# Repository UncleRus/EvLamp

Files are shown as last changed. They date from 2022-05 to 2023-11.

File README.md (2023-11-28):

# EvLamp

Clean implementation of Alex Guyver's FireLamp analogue in pure C for ESP32.

## What it does

Display beautiful effects on a multiple matrices of NxN WS2812B/SK6812/APA106/SM16703 LEDs.

### Features

- ~30 very beautiful effects from different authors, each with set of parameters
- WiFi connectivity in station or access point modes (support for DHCP/static IP addressing)
- [JSON HTTP API for remote controlling](API.md)
- Embedded webserver for remote controlling from browser
- *TODO: OTA*

## Hardware

You will need:

- ESP32 or ESP32-S3 (ESP32-S2/ESP32-C3/ESP32-C4 and others are not supported)
- One or more WS2812B/SK6812/APA106/SM16703 LED matrices
- 4 buttons:
    - Main: long press - On/Off, click - next effect
    - Up/Down: brightness up/down
    - Reset: long press - Reset settings to defaults

You can use the KiCad 7 project located in the [hardware directory](hardware) and containing
an example implementation: a schematic, a simple board and ready-made Gerber files for production
(compatible with JLCPCB requirements).

### LED matrix

The LEDs in the matrix are connected in series like a snake, starting from the bottom row:

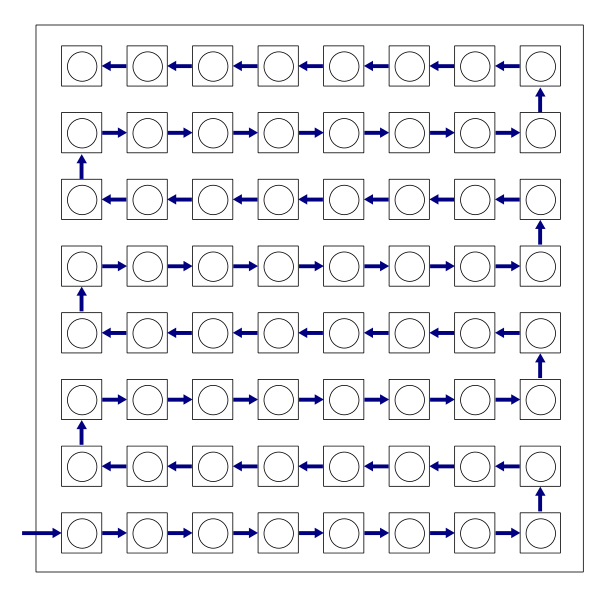
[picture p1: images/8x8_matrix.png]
8x8 matrix


The sizes of the most common matrices:
- 8x8
- 32x8
- 16x16

You can build your own matrix with widely available WS2812B/SK6812/APA106 LED strips.

The dimensions of the matrix side are limited to the range 8..128 and
number of pixels in matrix cannot be more than 1024.

I do not recommend using matrices with a large number of LEDs due to the maximum frame
rate limitations: for a matrix containing 512 LEDs, this limit is 60 fps, and for a matrix of
1024 LEDs maximal fps is 30. It is better to use multiple small matrices.

### Single matrix configuration

To control one matrix, only one GPIO pin of the microcontroller is needed:

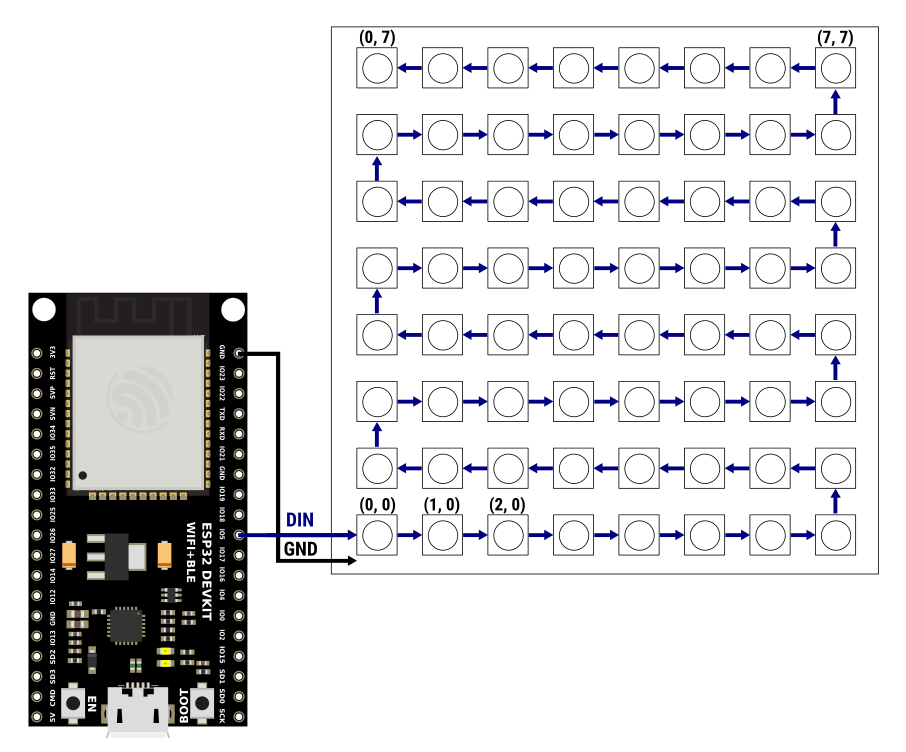
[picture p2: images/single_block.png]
Single matrix


This configuration is the simplest supported.

### Multiple LED matrices (blocks) configuration

You can connect up to 8 LED matrices of the same size to different GPIO pins and achieve high resolution
rendering of the effect. For example:

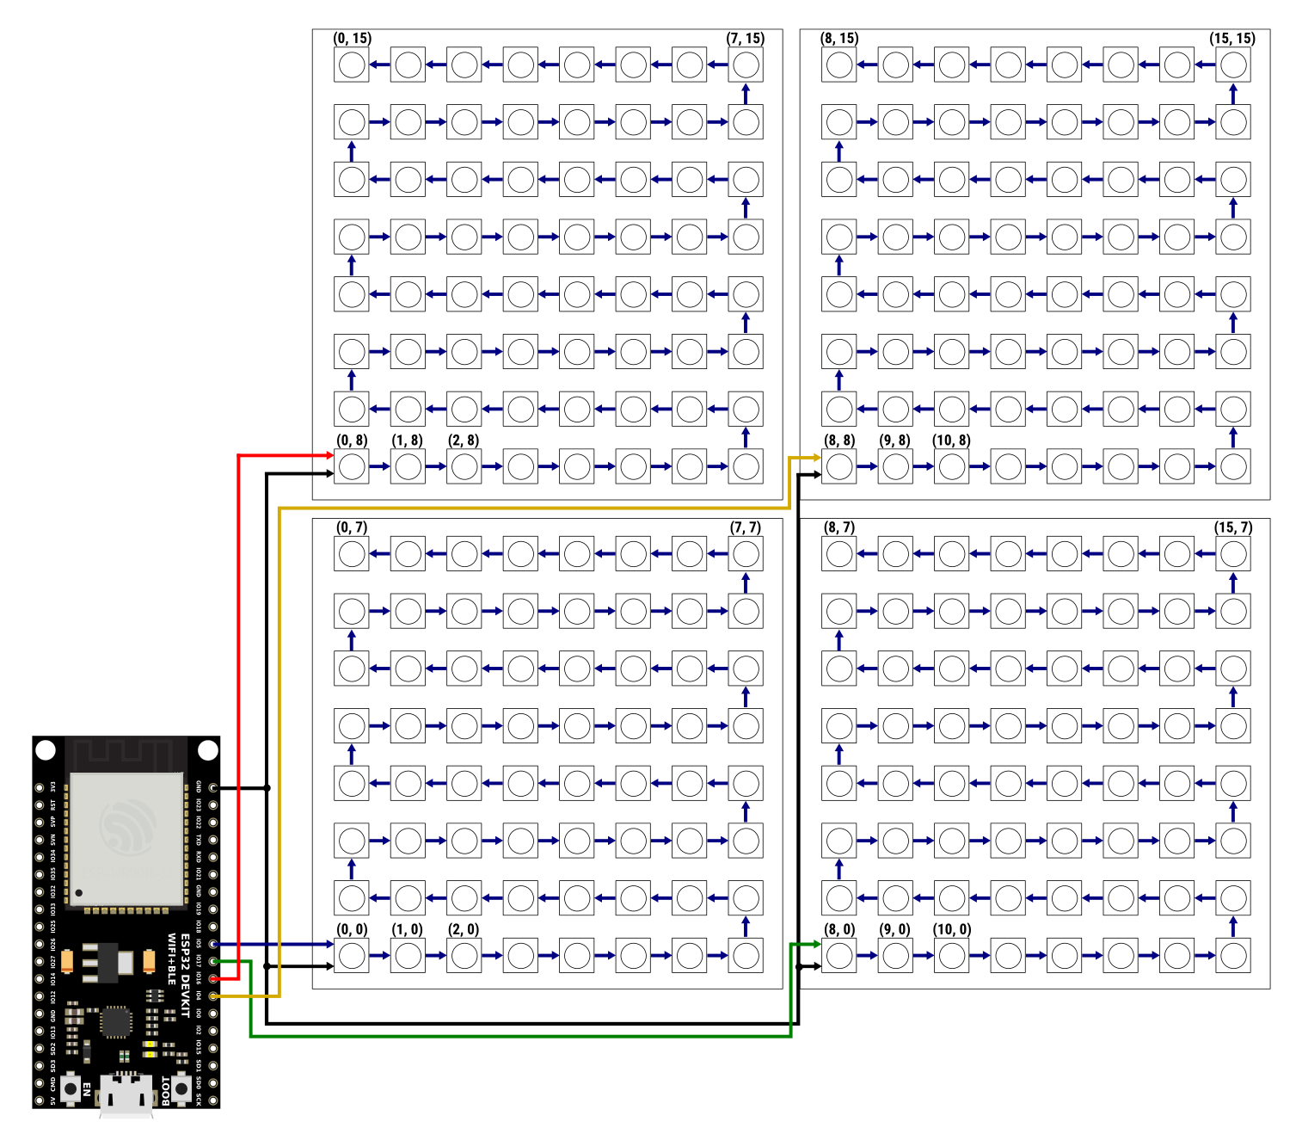
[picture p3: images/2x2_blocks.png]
4 blocks configuration example


### Minimal recommended configuration

1 block, 16x16 LEDs, 90 fps max.

### Maximal recommended configuration

2x4 blocks, each 32x16 LEDs.
Total screen dimensions: 64x64, 4096 LEDs, 60 fps max.

### Changing LED layout

Configure your LED layout at runtime by API or in browser ("Menu -> LEDs Settings"):

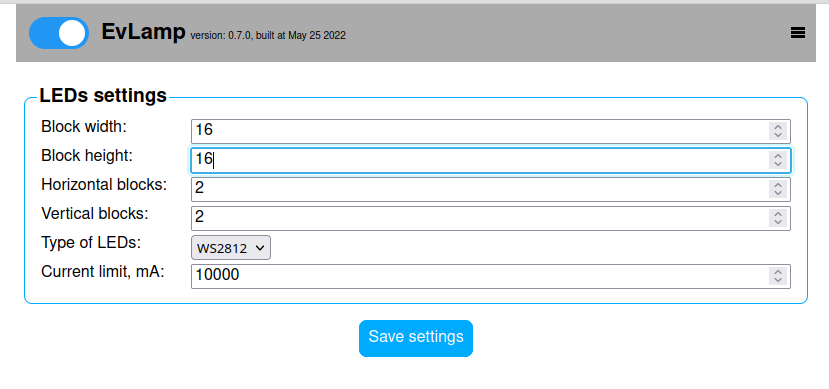
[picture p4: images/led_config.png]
LED layout configuration


## Changing default settings 

You can select GPIOs, set default WiFi config, LED layout and more in `idf.py menuconfig`
(`*** EvLamp configuration ***`). 

## How to build firmware

- Setup latest ESP-IDF master
- `git clone https://github.com/UncleRus/EvLamp.git`
- `git submodule init --recursive --remote`
- `idf.py menuconfig`
- `idf.py build`
- `idf.py erase-flash` (not necessary but recommended)
- `idf.py flash` to upload firmware to ESP

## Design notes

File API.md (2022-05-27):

# API

EvLamp provides a simple API based on HTTP GET and POST requests containing JSON data.

---

## Contents

- [Get firmware information](#get-firmware-information)
- [Get current WiFi settings](#get-current-wifi-settings)
- [Set WiFi settings](#set-wifi-settings)
- [Get current LED settings](#get-current-led-settings)
- [Set LED settings](#set-led-settings)
- [Reset system settings](#reset-system-settings)
- [Reboot device](#reboot-device)
- [Get current lamp state](#get-current-lamp-state)
- [Set lamp state](#set-lamp-state)
- [Get full list of effects and its parameters](#get-full-list-of-effects-and-its-parameters)
- [Reset parameters of all effects](#reset-parameters-of-all-effects)
- [Get current effect parameters](#get-current-effect-parameters)
- [Set effect parameters](#set-effect-parameters)

---

## Get firmware information

### Request

**GET** `/api/info`

### Response

```jsonc
{
  "app_name": <String, Application name, usually "EvLamp">,
  "app_version": <String, Application version>,
  "build_date": <String, Application build date>,
  "idf_ver": <String, Version of used ESP-IDF>
}
```

**Example**

```json
{
  "app_name": "EvLamp",
  "app_version": "0.6.3",
  "build_date": "May  2 2022",
  "idf_ver": "v5.0-dev-1829-ge29e96101d-dirty"
}
```

---

## Get current WiFi settings

### Request

**GET** `/api/settings/wifi`

### Response

```jsonc
{
  "mode": <Integer, WiFi mode. 1 - Station, 2 - Access point>,
  "ip": {
    /* IP settings for both AP and station modes */
    "dhcp": <Boolean, DHCP client enable in station mode>,
    "ip": <String, IP address. In station mode only makes sense if DHCP client is disabled>,
    "netmask": <String, Network mask. In station mode only makes sense if DHCP client is disabled>,
    "gateway": <String, Gateway IP address. In station mode only makes sense if DHCP client is disabled>,
    "dns": <String, IP-address of DNS server. In station mode only makes sense if DHCP client is disabled, 
          in AP mode used as fallback DNS server'>
  },
  "ap": {
    /* Access Point settings, only makes sense in AP mode */
    "ssid": <String, SSID of Access Point>,
    "channel": <Integer, Channel number>,
    "password": <String, Access Point WPA2 password. If empty, Access point will be in open mode>,
  },
  "sta": {
    /* Station settings, only makes sense in station mode */
    "ssid": <String, Contains the SSID of the network being connected to in station mode>,
    "password": <String, WPA2 password>,
  }
}
```

**Example**

```json
{
  "mode": 1,
  "ip": {
    "dhcp": true,
    "ip": "192.168.1.1",
    "netmask": "255.255.255.0",
    "gateway": "192.168.1.1",
    "dns": "192.168.1.1"
  },
  "ap": {
    "ssid": "EvLamp",
    "channel": 6,
    "password": ""
  },
  "sta": {
    "ssid": "MyHomeWiFi",
    "password": "SuperSecret"
  }
}
```

---

## Set WiFi settings

### Request

**POST** `/api/settings/wifi`

```jsonc
{
  "mode": <Integer, WiFi mode. 1 - Station, 2 - Access point>,
  "ip": {
    /* IP settings for both AP and station modes */
    "dhcp": <Boolean, DHCP client enable in station mode>,
    "ip": <String, IP address. In station mode only makes sense if DHCP client is disabled>,
    "netmask": <String, Network mask. In station mode only makes sense if DHCP client is disabled>,
    "gateway": <String, Gateway IP address. In station mode only makes sense if DHCP client is disabled>,
    "dns": <String, IP-address of DNS server. In station mode only makes sense if DHCP client is disabled, 
          in AP mode used as fallback DNS server'>
  },
  "ap": {
    /* Access Point settings, only makes sense in AP mode */
    "ssid": <String, SSID of Access Point>,
    "channel": <Integer, Channel number>,
    "password": <String, Access Point WPA2 password. If empty, Access point will be in open mode>,
  },
  "sta": {
    /* Station settings, only makes sense in station mode */
    "ssid": <String, Contains the SSID of the network being connected to in station mode>,
    "password": <String, WPA2 password>,
  }
}
```

### Response

```jsonc
{
  "result": <Integer, Result code. 0 - no errors>,
  "name": <String, Name of the result code, "ESP_OK" for result code 0>,
  "message": <String, Error message if result code != 0>
}
```

---

## Get current LED settings

### Request

**GET** `/api/settings/leds`

### Response

```jsonc
{
  "block_width": <Integer, single block (LED matrix) width (number of columns), 8..128>,
  "block_height": <Integer, single block (LED matrix) height (number of rows), 8..128>,
  "h_blocks": <Integer, number of blocks horizontally>,
  "v_blocks": <Integer, number of blocks vertically>,
  "type": <Integer, Type of LEDs. 0 - WS2812, 1 - SK6812, 2 - APA106, 3 - SM16703>,
  "current_limit": <Integer, Approximate limit of current consumed by all LEDs in milliamps.
                   The larger this value, the higher the maximum brightness.>,
}
```

*Note: The total number of blocks (h_blocks * v_blocks) should not be more than 8*

**Example**

Single 16x16 WS2812B matrix:

```json
{
  "block_width": 16,
  "block_height": 16,
  "h_blocks": 1,
  "v_blocks": 1,
  "type": 0,
  "current_limit": 5000
}
```

---

## Set LED settings

### Request

**POST** `/api/settings/leds`

```jsonc
{
  "block_width": <Integer, single block (LED matrix) width (number of columns), 8..128>,
  "block_height": <Integer, single block (LED matrix) height (number of rows), 8..128>,
  "h_blocks": <Integer, number of blocks horizontally>,
  "v_blocks": <Integer, number of blocks vertically>,
  "type": <Integer, Type of LEDs. 0 - WS2812, 1 - SK6812, 2 - APA106, 3 - SM16703>,
  "current_limit": <Integer, Approximate limit of current consumed by all LEDs in milliamps.
                   The larger this value, the higher the maximum brightness.>,
}
```

### Response

```jsonc
{
  "result": <Integer, Result code. 0 - no errors>,
  "name": <String, Name of the result code, "ESP_OK" for result code 0>,
  "message": <String, Error message if result code != 0>
}
```

---

## Reset system settings

Resets all system settings including both WiFi and LED settings to default values.
After resetting device must be rebooted.

### Request

**GET** `/api/settings/reset`

### Response

```jsonc
{
  "result": <Integer, Result code. 0 - no errors>,
  "name": <String, Name of the result code, "ESP_OK" for result code 0>,
  "message": <String, Error message if result code != 0>
}
```

---

## Reboot device

### Request

**GET** `/api/reboot`

### Response

No response, device just reboots.

---

## Get current lamp state

### Request

**GET** `/api/lamp/state`

### Response

```jsonc
{
  "on": <Boolean, true - Lamp is on, false - Lamp is off>,
  "effect": <Integer, Current effect ID, 0-based>,
  "brightness": <Integer, LED matrix brightness, 0..255>,
  "fps": <Integer, Frames per seconds, 0..120>
}
```

---

## Set lamp state

With this function you can switch LEDs on and off, change current effect, brightness and FPS.

### Request

**POST** `/api/lamp/state`

```jsonc
{
  "on": <Boolean, true - Lamp is on, false - Lamp is off>,
  "effect": <Integer, Selected effect ID, 0-based>,
  "brightness": <Integer, LED matrix brightness, 0..255>,
  "fps": <Integer, Frames per seconds, 0..120>
}
```

Any item in request can be omitted. For example, you can switch off the lamp with this POST:
```json
{ "on": false }
```
or change effect to "Fire" (id = 1) and set brightness:
```json
{ "effect": 1, "brightness": 50 }
```

### Response

```jsonc
{
  "result": <Integer, Result code. 0 - no errors>,
  "name": <String, Name of the result code, "ESP_OK" for result code 0>,
  "message": <String, Error message if result code != 0>
}
```

---

## Get full list of effects and its parameters

### Request

**GET** `/api/effects`

### Response

```jsonc
[
  {
    "name": <String, Effect name>,
    "params": [
      {
        "name": <String, Parameter name>,
        "min": <Integer, Minimal value>,
        "max": <Integer, Maximal value>,
        "default": <Integer, Default value>,
        "value": <Integer, Current value>
      },
      ...
    ]
  },
  ...
]
```

The effect index in the response array is the effect ID.
The parameter's index in the effect's parameter list is the parameter ID.

**Example**

```json
[{
    "name": "Color lamp",
    "params": [{
        "name": "Red",
        "min": 0,
        "max": 255,
        "default": 255,
        "value": 255
      }, {
        "name": "Green",
        "min": 0,
        "max": 255,
        "default": 159,
        "value": 159
      }, {
        "name": "Blue",
        "min": 0,
        "max": 255,
        "default": 70,
        "value": 70
      }]
  },
  {
    "name": "Fire",
    "params": [{
        "name": "Palette",
        "min": 0,
        "max": 7,
        "default": 0,
        "value": 0
      }, {
        "name": "Scale",
        "min": 10,
        "max": 100,
        "default": 60,
        "value": 60
      }]
  },
  ... 
  {
    "name": "Fireflies",
    "params": [{
        "name": "Number of fireflies",
        "min": 4,
        "max": 48,
        "default": 16,
        "value": 16
      }, {
        "name": "Chaotic movements",
        "min": 0,
        "max": 1,
        "default": 1,
        "value": 1
      }, {
        "name": "Speed",
        "min": 1,
        "max": 255,
        "default": 255,
        "value": 255
      }, {
        "name": "Update time",
        "min": 1,
        "max": 10,
        "default": 3,
        "value": 3
      }]
  }]
```

---

## Reset parameters of all effects

### Request

**GET** `/api/effects/reset`

### Response

```jsonc
{
  "result": <Integer, Result code. 0 - no errors>,
  "name": <String, Name of the result code, "ESP_OK" for result code 0>,
  "message": <String, Error message if result code != 0>
}
```

---

## Get current effect parameters

### Request

**GET** `/api/lamp/effect`

### Response

```jsonc
{
  "effect": <Integer, Current effect ID, 0-based>,
  "params": [
    {
      "name": <String, Parameter name>,
      "min": <Integer, Minimal value>,
      "max": <Integer, Maximal value>,
      "default": <Integer, Default value>,
      "value": <Integer, Current value>
    },
    ...
  ]
}
```

**Example**

```json
{
  "effect": 1,
  "params": [
    {
      "name": "Palette",
      "min": 0,
      "max": 7,
      "default": 0,
      "value": 0
    },
    {
      "name": "Scale",
      "min": 10,
      "max": 100,
      "default": 60,
      "value": 60
    }
  ]
}
```

---

## Set effect parameters

### Request

**POST** `/api/lamp/effect`

```jsonc
{
  "effect": <Integer, Effect ID, 0-based>,
  "params": [
    <Integer, 0 parameter value>,
    ...
    <Integer, n parameter value>,
  ]
}
```

**Example**

Set Palette = 1 and Scale = 60 for the "Fire" effect. 

```json
{
  "effect": 1,
  "params": [ 1, 60 ]
}
```

### Response

```jsonc
{
  "result": <Integer, Result code. 0 - no errors>,
  "name": <String, Name of the result code, "ESP_OK" for result code 0>,
  "message": <String, Error message if result code != 0>
}
```

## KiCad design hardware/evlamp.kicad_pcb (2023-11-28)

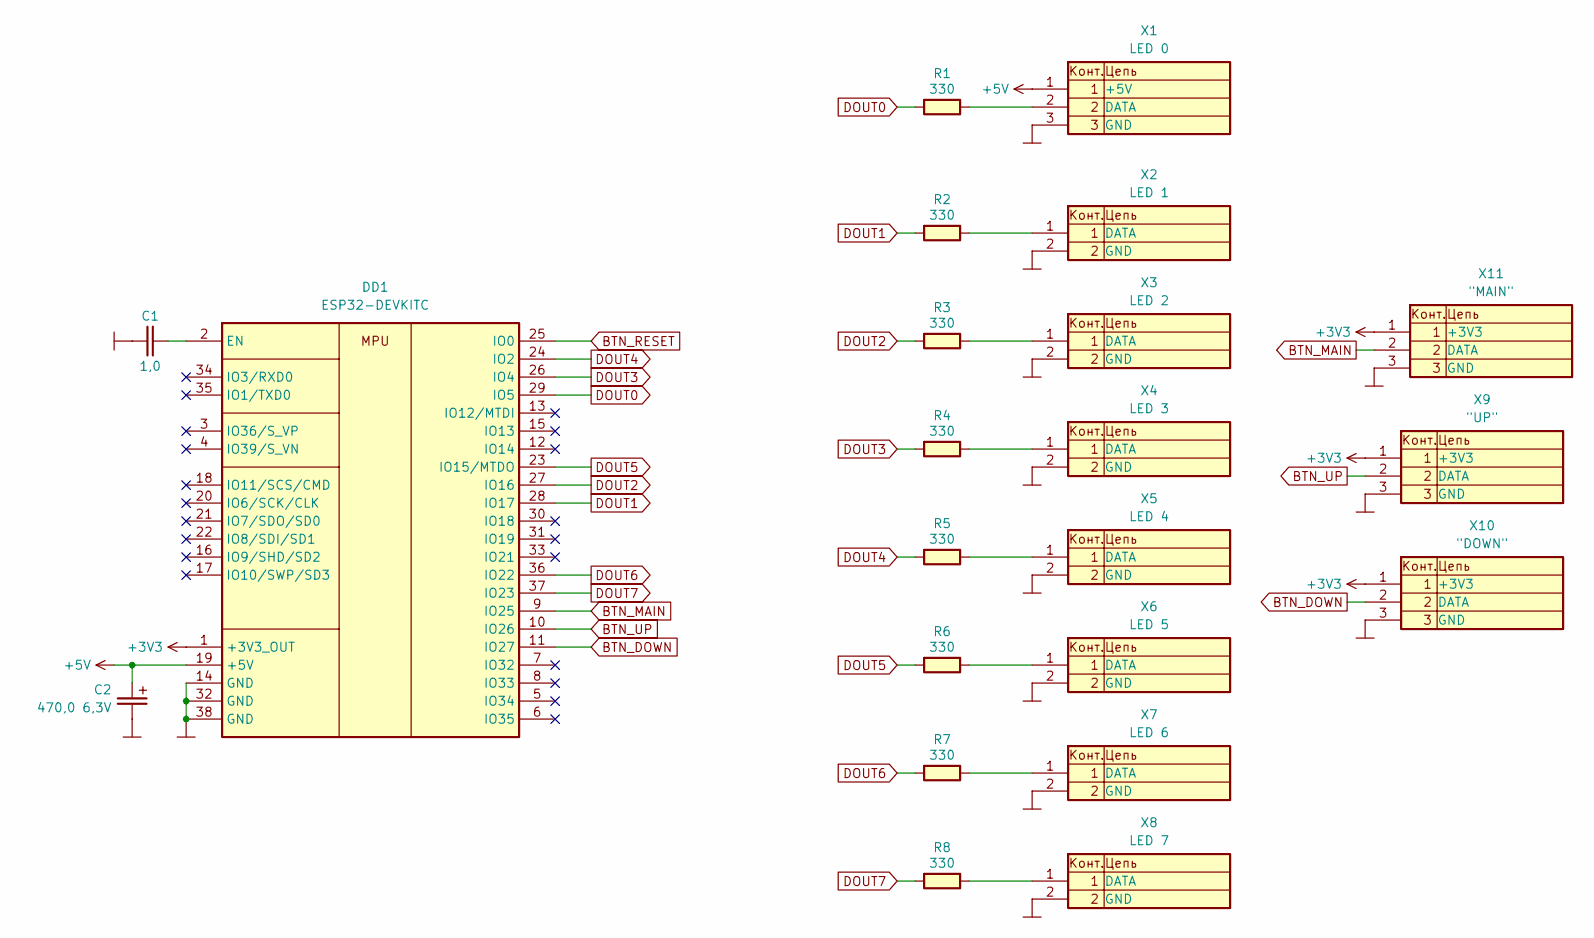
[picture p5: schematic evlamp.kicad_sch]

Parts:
C1: 1,0; C_0805_2012Metric_Pad1.18x1.45mm_HandSolder
C2: 470,0 6,3V; CP_EIA-7343-31_Kemet-D_Pad2.25x2.55mm_HandSolder
DD1: ESP32-DEVKITC
R1, R2, R3, R4, R5, R6, R7, R8: 330; R_0805_2012Metric_Pad1.20x1.40mm_HandSolder
X1: LED 0; TerminalBlock_bornier-3_P5.08mm
X2: LED 1; TerminalBlock_bornier-2_P5.08mm
X3: LED 2; TerminalBlock_bornier-2_P5.08mm
X4: LED 3; TerminalBlock_bornier-2_P5.08mm
X5: LED 4; TerminalBlock_bornier-2_P5.08mm
X6: LED 5; TerminalBlock_bornier-2_P5.08mm
X7: LED 6; TerminalBlock_bornier-2_P5.08mm
X8: LED 7; TerminalBlock_bornier-2_P5.08mm
X9: "UP"; PinHeader_1x03_P2.54mm_Vertical
X10: "DOWN"; PinHeader_1x03_P2.54mm_Vertical
X11: "MAIN"; PinHeader_1x03_P2.54mm_Vertical

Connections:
+3V3: DD1.1 (+3V3_OUT), X9.1, X10.1, X11.1
+5V: C2.1, DD1.19 (+5V), X1.1
BTN_DOWN: DD1.11 (IO27), X10.2
BTN_MAIN: DD1.9 (IO25), X11.2
BTN_RESET: DD1.25 (IO0)
BTN_UP: DD1.10 (IO26), X9.2
DOUT0: DD1.29 (IO5), R1.1 (L)
DOUT1: DD1.28 (IO17), R2.1 (L)
DOUT2: DD1.27 (IO16), R3.1 (L)
DOUT3: DD1.26 (IO4), R4.1 (L)
DOUT4: DD1.24 (IO2), R5.1 (L)
DOUT5: DD1.23 (IO15/MTDO), R6.1 (L)
DOUT6: DD1.36 (IO22), R7.1 (L)
DOUT7: DD1.37 (IO23), R8.1 (L)
GND: C1.1, C2.2, DD1.14 (GND), DD1.32 (GND), DD1.38 (GND), X1.3, X2.2, X3.2, X4.2, X5.2, X6.2, X7.2, X8.2, X9.3, X10.3, X11.3
unnamed: C1.2, DD1.2 (EN)
unnamed: R1.2 (R), X1.2
unnamed: R2.2 (R), X2.1
unnamed: R3.2 (R), X3.1
unnamed: R4.2 (R), X4.1
unnamed: R5.2 (R), X5.1
unnamed: R6.2 (R), X6.1
unnamed: R7.2 (R), X7.1
unnamed: R8.2 (R), X8.1

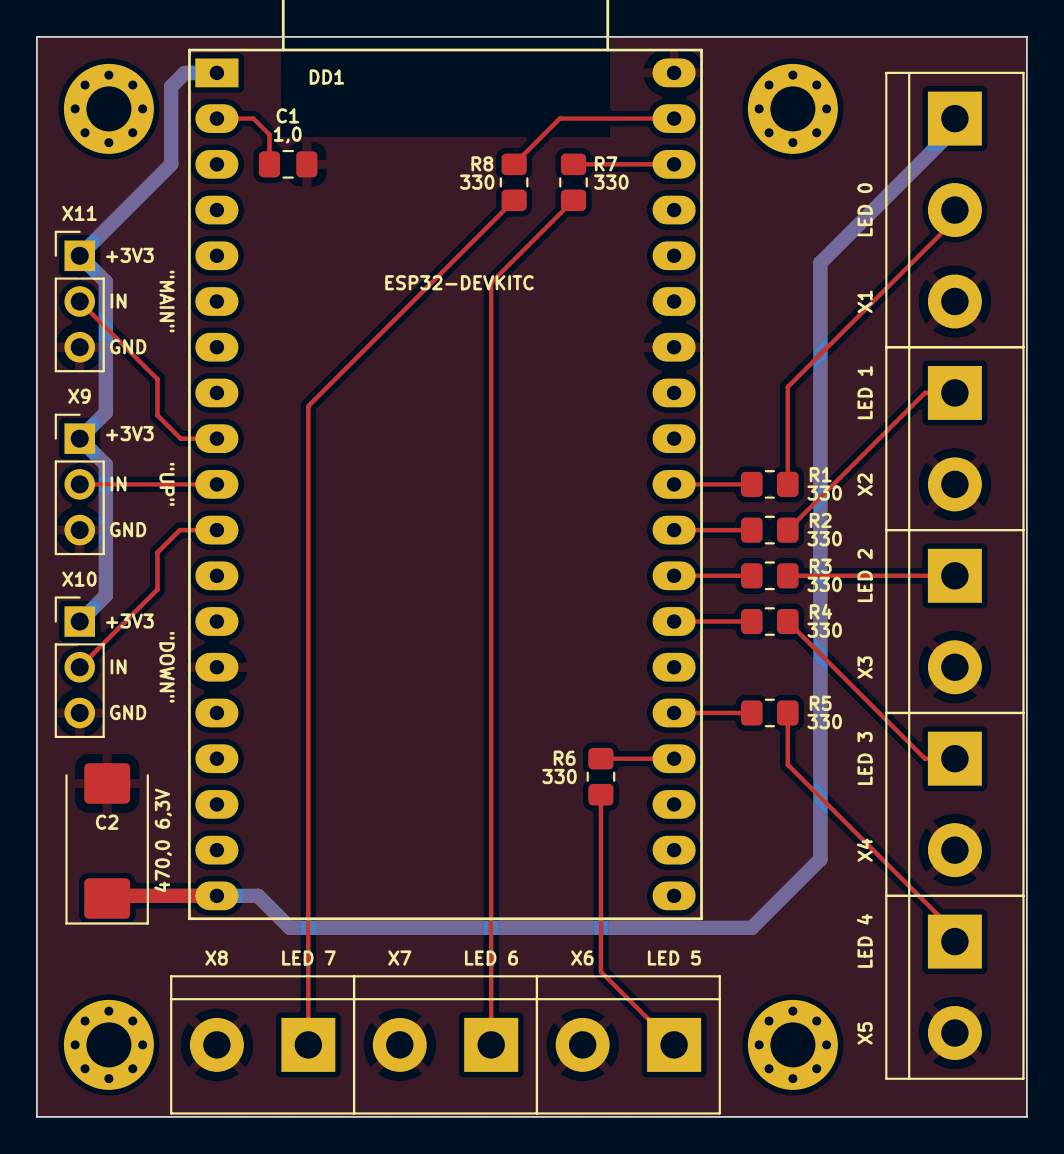
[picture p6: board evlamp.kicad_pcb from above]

Board: 2 copper layers, 55.0 x 60.0 mm, 22 parts (0 on the bottom side), 23 nets.

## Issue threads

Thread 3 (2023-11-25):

ESP32-S3 compiling but not working

Alfred1975, 2023-11-25:
Hello!

I tried to run your project on ESP32-S3. Its compiling, working, button and wifi are ok but leds are not working.

SImple RMT example is working from IDF v5 with the same leds and GPIO.

I see that you indicated that not all the ESP32 chips are compatible. S3 is also not compatible?

But no errors in Serial monitor also..

Regards!

Alfred1975, 2023-11-27:
Hello!

As I indicated in my first post the [default example for the led_strip driver from esp-idf-lib] is working.

But nothing happen with leds when I flash your project. The same GPIO.

From wifi or button I change the aniation but nothing happen with leds...

UncleRus, 2023-11-27:
Can I see the serial console output log?

Alfred1975, 2023-11-27:
ESP-ROM:esp32s3-20210327
Build:Mar 27 2021
rst:0x1 (POWERON),boot:0x2b (SPI_FAST_FLASH_BOOT)
SPIWP:0xee
mode:DOUT, clock div:1
load:0x3fce3818,len:0x1750
load:0x403c9700,len:0x4
load:0x403c9704,len:0xc00
load:0x403cc700,len:0x2e04
entry 0x403c9908
I (27) boot: ESP-IDF v5.1.2 2nd stage bootloader
I (27) boot: compile time Nov 24 2023 19:08:04
I (27) boot: Multicore bootloader
I (30) boot: chip revision: v0.2
I (34) boot.esp32s3: Boot SPI Speed : 80MHz
I (39) boot.esp32s3: SPI Mode       : DOUT
I (43) boot.esp32s3: SPI Flash Size : 8MB
I (48) boot: Enabling RNG early entropy source...
I (54) boot: Partition Table:
I (57) boot: ## Label            Usage          Type ST Offset   Length
I (64) boot:  0 nvs              WiFi data        01 02 00009000 00004000
I (72) boot:  1 otadata          OTA data         01 00 0000d000 00002000
I (79) boot:  2 phy_init         RF data          01 01 0000f000 00001000
I (87) boot:  3 factory          factory app      00 00 00010000 00150000
I (94) boot:  4 ota_0            OTA app          00 10 00160000 00150000
I (102) boot:  5 ota_1            OTA app          00 11 002b0000 00150000
I (109) boot: End of partition table
I (114) boot: Defaulting to factory image
I (118) esp_image: segment 0: paddr=00010020 vaddr=3c0a0020 size=45d14h (285972) map
I (182) esp_image: segment 1: paddr=00055d3c vaddr=3fc97e00 size=0530ch ( 21260) load
I (187) esp_image: segment 2: paddr=0005b050 vaddr=40374000 size=04fc8h ( 20424) load
I (192) esp_image: segment 3: paddr=00060020 vaddr=42000020 size=9e9d8h (649688) map
I (321) esp_image: segment 4: paddr=000fea00 vaddr=40378fc8 size=0ed98h ( 60824) load
I (343) boot: Loaded app from partition at offset 0x10000
I (344) boot: Disabling RNG early entropy source...
I (355) cpu_start: Multicore app
I (355) cpu_start: Pro cpu up.
I (356) cpu_start: Starting app cpu, entry point is 0x4037555c
0x4037555c: call_start_cpu1 at C:/esp/esp-idf/components/esp_system/port/cpu_start.c:157

I (0) cpu_start: App cpu up.
I (374) cpu_start: Pro cpu start user code
I (374) cpu_start: cpu freq: 160000000 Hz
I (374) cpu_start: Application information:
I (377) cpu_start: Project name:     EvLamp
I (382) cpu_start: App version:      0.7.3
I (386) cpu_start: Compile time:     Nov 24 2023 19:07:27
I (392) cpu_start: ELF file SHA256:  48d1208000b0d2b3...
I (398) cpu_start: ESP-IDF:          v5.1.2
I (403) cpu_start: Min chip rev:     v0.0
I (408) cpu_start: Max chip rev:     v0.99
I (413) cpu_start: Chip rev:         v0.2
I (418) heap_init: Initializing. RAM available for dynamic allocation:
I (425) heap_init: At 3FCA1570 len 000481A0 (288 KiB): DRAM
I (431) heap_init: At 3FCE9710 len 00005724 (21 KiB): STACK/DRAM
I (438) heap_init: At 3FCF0000 len 00008000 (32 KiB): DRAM
I (444) heap_init: At 600FE010 len 00001FD8 (7 KiB): RTCRAM
I (451) spi_flash: detected chip: gd
I (454) spi_flash: flash io: dout
W (459) rmt(legacy): legacy driver is deprecated, please migrate to `driver/rmt_tx.h` and/or `driver/rmt_rx.h`
I (469) sleep: Configure to isolate all GPIO pins in sleep state
I (476) sleep: Enable automatic switching of GPIO sleep configuration
I (483) app_start: Starting scheduler on CPU0
I (488) app_start: Starting scheduler on CPU1
I (488) main_task: Started on CPU0
I (498) main_task: Calling app_main()
I (502) EvLamp: Starting EvLamp
I (505) EvLamp: Free heap: 336416 bytes
I (587) EvLamp: Effect 0: 'Color lamp'
I (588) EvLamp:     Red: 255 (min 0, max 255, def 255)
I (589) EvLamp:     Green: 159 (min 0, max 255, def 159)
I (593) EvLamp:     Blue: 70 (min 0, max 255, def 70)
I (599) EvLamp: Effect 1: 'Fire'
I (603) EvLamp:     Palette: 2 (min 0, max 7, def 0)
I (608) EvLamp:     Scale: 60 (min 10, max 100, def 60)
I (614) EvLamp: Effect 2: 'Sparkles'
I (619) EvLamp:     Number of sparkles: 10 (min 1, max 50, def 10)
I (625) EvLamp:     Fadeout speed: 80 (min 10, max 150, def 80)
I (632) EvLamp: Effect 3: 'Lava'
I (636) EvLamp:     Scale: 40 (min 5, max 100, def 40)
I (642) EvLamp:     Speed: 15 (min 0, max 50, def 15)
I (648) EvLamp:     Mode: 1 (min 0, max 2, def 1)
I (653) EvLamp:     Palette: 0 (min 0, max 13, def 0)
I (658) EvLamp: Effect 4: 'Waterfall'
I (663) EvLamp:     Mode: 0 (min 0, max 2, def 0)
I (668) EvLamp:     Color: 160 (min 0, max 255, def 160)
I (674) EvLamp:     Cooling: 10 (min 5, max 100, def 10)
I (680) EvLamp:     Sparking: 60 (min 20, max 200, def 60)
I (686) EvLamp: Effect 5: 'Plasma waves'
I (691) EvLamp:     Speed: 40 (min 1, max 255, def 40)
I (697) EvLamp: Effect 6: 'DNA helix'
I (701) EvLamp:     Rotation speed: 50 (min 10, max 100, def 50)
I (708) EvLamp:     Spiral size: 5 (min 1, max 10, def 5)
I (714) EvLamp:     Add white border: 1 (min 0, max 1, def 1)
I (720) EvLamp: Effect 7: 'Matrix'
I (724) EvLamp:     Density: 150 (min 0, max 255, def 150)
I (730) EvLamp: Effect 8: 'Crazy bees'
I (735) EvLamp:     Number of bees: 3 (min 1, max 10, def 3)
I (741) EvLamp:     Bee hue: 100 (min 0, max 255, def 100)
I (748) EvLamp:     Bee saturation: 0 (min 0, max 255, def 0)
I (754) EvLamp: Effect 9: 'Rain'
I (758) EvLamp:     Colored: 0 (min 0, max 1, def 0)
I (764) EvLamp:     Hue: 128 (min 0, max 255, def 128)
I (769) EvLamp:     Density: 50 (min 0, max 100, def 50)
I (775) EvLamp:     Tail length: 150 (min 100, max 200, def 150)
I (782) EvLamp: Effect 10: 'Rainbow'
I (786) EvLamp:     Direction: 0 (min 0, max 2, def 0)
I (792) EvLamp:     Scale: 20 (min 1, max 50, def 20)
I (798) EvLamp:     Speed: 10 (min 1, max 40, def 5)
I (803) EvLamp: Effect 11: 'Rays'
I (807) EvLamp:     Speed: 10 (min 0, max 50, def 10)
I (813) EvLamp:     Min rays: 3 (min 1, max 10, def 3)
I (819) EvLamp:     Max rays: 6 (min 1, max 20, def 6)
I (825) EvLamp: Effect 12: 'Metaballs'
I (829) EvLamp:     Palette: 0 (min 0, max 2, def 0)
I (835) EvLamp:     Balls: 3 (min 2, max 6, def 3)
I (840) EvLamp: Effect 13: 'Water'
I (844) EvLamp:     Hue: 150 (min 0, max 255, def 150)
I (850) EvLamp:     Saturation: 255 (min 0, max 255, def 255)
I (857) EvLamp:     Speed: 30 (min 0, max 54, def 30)
I (862) EvLamp: Effect 14: 'Holiday lights'
I (867) EvLamp:     Mode: 0 (min 0, max 3, def 0)
I (873) EvLamp:     Speed: 8 (min 1, max 20, def 8)
I (878) EvLamp: Effect 15: 'Hoop'
I (882) EvLamp:     Speed: 15 (min 1, max 50, def 15)
I (888) EvLamp: Effect 16: 'Twister'
I (892) EvLamp:     Speed: 30 (min 0, max 40, def 30)
I (898) EvLamp:     Add black border: 1 (min 0, max 1, def 1)
I (904) EvLamp:     Iridescent colors: 0 (min 0, max 1, def 0)
I (911) EvLamp: Effect 17: 'Flower'
I (915) EvLamp:     Speed: 100 (min 1, max 255, def 100)
I (921) EvLamp:     Diameter: 128 (min 50, max 150, def 128)
I (927) EvLamp: Effect 18: 'Polar lights'
I (932) EvLamp:     Speed: 127 (min 1, max 255, def 127)
I (938) EvLamp:     Scale: 60 (min 1, max 255, def 60)
I (944) EvLamp:     Palette: 0 (min 0, max 1, def 0)
I (949) EvLamp:     Height adjustment: 50 (min 1, max 255, def 50)
I (956) EvLamp: Effect 19: 'Gif image'
I (961) EvLamp:     File: 0 (min 0, max 10, def 0)
I (966) EvLamp: Effect 20: 'Relax'
I (970) EvLamp:     Speed: 15 (min 1, max 100, def 15)
I (976) EvLamp:     Start hue: 100 (min 0, max 255, def 100)
I (982) EvLamp:     Saturation: 255 (min 0, max 255, def 255)
I (989) EvLamp:     Pixels to update: 1 (min 1, max 50, def 1)
I (995) EvLamp: Effect 21: 'Radiant wheel'
I (1000) EvLamp:     Rotation speed: 60 (min 0, max 255, def 60)
I (1007) EvLamp:     Hue 1: 0 (min 0, max 255, def 0)
I (1013) EvLamp:     Saturation 1: 255 (min 0, max 255, def 255)
I (1019) EvLamp:     Hue 2: 150 (min 0, max 255, def 150)
I (1025) EvLamp:     Saturation 2: 0 (min 0, max 255, def 0)
I (1032) EvLamp:     Number of rays: 3 (min 2, max 6, def 3)
I (1038) EvLamp: Effect 22: 'Peacock tail'
I (1043) EvLamp:     Speed: 200 (min 1, max 255, def 200)
I (1049) EvLamp:     Scale: 4 (min 1, max 10, def 4)
I (1055) EvLamp:     Saturation: 255 (min 0, max 255, def 255)
I (1061) EvLamp: Effect 23: 'Colors'
I (1065) EvLamp:     Speed: 192 (min 128, max 254, def 192)
I (1072) EvLamp:     Minimal saturation: 128 (min 1, max 255, def 128)
I (1079) EvLamp:     Maximal saturation: 255 (min 1, max 255, def 255)
I (1086) EvLamp: Effect 24: 'Diagonal movements'
I (1091) EvLamp:     Speed: 5 (min 1, max 10, def 5)
I (1097) EvLamp: Effect 25: 'Whirls'
I (1101) EvLamp:     Count: 20 (min 10, max 50, def 20)
I (1107) EvLamp:     Scale: 26 (min 5, max 50, def 26)
I (1113) EvLamp:     Palette: 0 (min 0, max 13, def 0)
I (1119) EvLamp:     Fadeout: 50 (min 10, max 250, def 50)
I (1125) EvLamp:     Time scale: 10 (min 1, max 10, def 10)
I (1131) EvLamp: Effect 26: 'Sun radiation'
I (1136) EvLamp:     Size: 8 (min 4, max 32, def 8)
I (1141) EvLamp:     Palette: 10 (min 0, max 13, def 10)
I (1147) EvLamp: Effect 27: 'Flight of spaceships'
I (1153) EvLamp:     Number of ships: 8 (min 2, max 16, def 8)
I (1159) EvLamp:     Direction change time: 5 (min 1, max 60, def 5)
I (1166) EvLamp: Effect 28: 'Fireflies'
I (1171) EvLamp:     Number of fireflies: 16 (min 4, max 48, def 16)
I (1178) EvLamp:     Chaotic movement: 1 (min 0, max 1, def 1)
I (1185) EvLamp:     Speed: 255 (min 1, max 255, def 255)
I (1191) EvLamp:     Update time: 3 (min 1, max 10, def 3)
I (1196) EvLamp: Effect 29: 'Tunnel'
I (1201) EvLamp:     Speed: 90 (min 1, max 170, def 90)
I (1207) EvLamp: Effect 30: 'Colored dunes'
I (1212) EvLamp:     Speed: 5 (min 1, max 40, def 5)
I (1217) EvLamp:     Palette: 1 (min 0, max 13, def 1)
I (1223) EvLamp: Effect 31: 'Octopus'
I (1228) EvLamp:     Speed: 3 (min 1, max 10, def 3)
I (1233) EvLamp:     Legs: 3 (min 2, max 10, def 3)
I (1238) EvLamp: Effect 32: 'Nuclear Noise'
I (1244) EvLamp:     Speed: 3 (min 1, max 10, def 3)
I (1249) EvLamp: Effect parameters loaded
I (1254) EvLamp: Maximal LED brightness: 255
I (1259) EvLamp: Surface configuration: 8x8 (64) LEDs, 1x1 (1) blocks
I (1266) EvLamp: Waiting for surface task to be ready...
I (1266) EvLamp: Block 0 LED strip config: 8x8, GPIO = 17, type = 0
I (1279) EvLamp: Surface ready
I (1283) EvLamp: Animation stopped
I (1288) EvLamp: Animation started
I (1291) EvLamp: Switched to effect 'Rainbow' (10)
I (1297) EvLamp: Starting WiFi in access point mode
I (1303) pp: pp rom version: e7ae62f
I (1306) net80211: net80211 rom version: e7ae62f
I (1313) wifi:wifi driver task: 3fcae2a0, prio:23, stack:6656, core=0
I (1337) wifi:wifi firmware version: 91b9630
I (1337) wifi:wifi certification version: v7.0
I (1337) wifi:config NVS flash: enabled
I (1338) wifi:config nano formating: disabled
I (1342) wifi:Init data frame dynamic rx buffer num: 32
I (1347) wifi:Init static rx mgmt buffer num: 5
I (1351) wifi:Init management short buffer num: 32
I (1355) wifi:Init dynamic tx buffer num: 32
I (1359) wifi:Init static tx FG buffer num: 2
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
UncleRus, 2023-11-27:
Thank you. I see absolutely nothing abnormal in the logs. Do you have an oscilloscope or logic analyzer? And if there is, could you connect the device to the output GPIO and make sure that there is no signal there?

Alfred1975, 2023-11-27:
I spend a lot of time trying to find a problem but the only solution after a lot of advices was to run `esptool flash_erase` and then flash your project.

After the full erase everything is seems working OK.

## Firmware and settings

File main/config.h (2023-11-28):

#ifndef EVLAMP_CONFIG_H_
#define EVLAMP_CONFIG_H_

////////////////////////////////////////////////////////////////////////////////
/// System

#if !defined(CONFIG_IDF_TARGET_ESP32) && !defined(CONFIG_IDF_TARGET_ESP32S3)
    #error Unsupported target
#endif

#define APP_NAME "EvLamp"

////////////////////////////////////////////////////////////////////////////////
/// Settings

#define SETTINGS_MAGIC 0xbeef001a

#ifdef CONFIG_EL_WIFI_MODE_AP
    #define DEFAULT_WIFI_MODE WIFI_MODE_AP
#else
    #define DEFAULT_WIFI_MODE WIFI_MODE_STA
#endif

#if CONFIG_EL_WIFI_DHCP
    #define DEFAULT_WIFI_DHCP true
#else
    #define DEFAULT_WIFI_DHCP false
#endif

#define DEFAULT_WIFI_AP_MAXCONN 5

#if CONFIG_EL_LED_TYPE_APA106
    #define DEFAULT_LED_TYPE LED_STRIP_APA106
#elif CONFIG_EL_LED_TYPE_SK6812
    #define DEFAULT_LED_TYPE LED_STRIP_SK6812
#elif CONFIG_EL_LED_TYPE_SM16703
    #define DEFAULT_LED_TYPE LED_STRIP_SM16703
#else
    #define DEFAULT_LED_TYPE LED_STRIP_WS2812
#endif

#if CONFIG_EL_MATRIX_ROTATION_90
    #define DEFAULT_MATRIX_ROTATION MATRIX_ROTATION_90
#elif CONFIG_EL_MATRIX_ROTATION_180
    #define DEFAULT_MATRIX_ROTATION MATRIX_ROTATION_180
#elif CONFIG_EL_MATRIX_ROTATION_270
    #define DEFAULT_MATRIX_ROTATION MATRIX_ROTATION_270
#else
    #define DEFAULT_MATRIX_ROTATION MATRIX_ROTATION_0
#endif

////////////////////////////////////////////////////////////////////////////////
/// Bus

#define BUS_QUEUE_LEN 5
#define BUS_TIMEOUT_MS 500
#define BUS_EVENT_DATA_SIZE 64

////////////////////////////////////////////////////////////////////////////////
/// Main task

#define MAIN_TASK_STACK_SIZE 8192
#define MAIN_TASK_PRIORITY 5

////////////////////////////////////////////////////////////////////////////////
/// Surface

#define FPS_MAX 120
#define SURFACE_TASK_STACK_SIZE 8192
#define MAX_SURFACE_BLOCKS 8 // RMT_CHANNEL_MAX
#define MAX_BLOCK_LEDS 1024
#define MIN_BLOCK_SIZE 8
#define MAX_BLOCK_SIZE 128

#if CONFIG_EL_MATRIX_H_BLOCKS * CONFIG_EL_MATRIX_V_BLOCKS > MAX_SURFACE_BLOCKS
    #error Too much LED blocks!
#endif

////////////////////////////////////////////////////////////////////////////////
/// Webserver

#define HTTPD_STACK_SIZE 32768
#define MAX_POST_SIZE 4096

#endif /* EVLAMP_CONFIG_H_ */

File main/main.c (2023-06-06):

#include "common.h"
#include "settings.h"
#include "wifi.h"
#include "bus.h"
#include "effect.h"
#include "surface.h"
#include "input.h"
#include "webserver.h"

inline static void process_button_event(event_t *e)
{
    size_t button_id = *((size_t *)e->data);

    ESP_LOGD(TAG, "Got button %d event %d", button_id, e->type);

    if (button_id == INPUT_BTN_RESET)
    {
        if (e->type == EVENT_BUTTON_PRESSED_LONG)
        {
            ESP_ERROR_CHECK(effects_reset());
            ESP_ERROR_CHECK(sys_settings_reset());
            ESP_ERROR_CHECK(vol_settings_reset());
            esp_restart();
        }
        return;
    }

    bool playing = surface_is_playing();
    if (button_id == INPUT_BTN_MAIN)
    {
        switch (e->type)
        {
            case EVENT_BUTTON_CLICKED:
                if (playing)
                    surface_next_effect();
                break;
            case EVENT_BUTTON_PRESSED_LONG:
                if (playing)
                    surface_stop();
                else
                    surface_play();
                break;
            default:
                break;
        }
        return;
    }

    if (!playing) return;

    // up/down
    if (e->type == EVENT_BUTTON_CLICKED &&
            (button_id == INPUT_BTN_UP || button_id == INPUT_BTN_DOWN))
    {
        surface_increment_brightness(button_id == INPUT_BTN_UP ? 5 : -5);
    }
}

static void main_loop(void *arg)
{
    event_t e;
    esp_err_t err;

    while (1)
    {
        if (bus_receive_event(&e, 1000) != ESP_OK)
            continue;

        switch (e.type)
        {
            case EVENT_BUTTON_CLICKED:
            case EVENT_BUTTON_PRESSED_LONG:
                process_button_event(&e);
                break;

            case EVENT_NETWORK_UP:
                ESP_LOGI(TAG, "Network is up, restarting HTTPD...");
                err = webserver_restart();
                if (err != ESP_OK)
                    ESP_LOGW(TAG, "Error starting HTTPD: %d (%s)", err, esp_err_to_name(err));
                break;

            case EVENT_NETWORK_DOWN:
                ESP_LOGI(TAG, "Network is down");
                break;

            default:
                ESP_LOGI(TAG, "Unprocessed event %d", e.type);
        }
    }
}

void app_main()
{
    ESP_LOGI(TAG, "Starting " APP_NAME);
    ESP_LOGI(TAG, "Free heap: %lu bytes", esp_get_free_heap_size());

    // Initialize NVS
    ESP_ERROR_CHECK(settings_init());
    // Load system settings from NVS
    ESP_ERROR_CHECK(sys_settings_load());
    // Load volatile settings
    ESP_ERROR_CHECK(vol_settings_load());
    // Load effect parameters
    ESP_ERROR_CHECK(effects_init());
    // Init surface
    ESP_ERROR_CHECK(surface_init());

    // Initialize bus
    ESP_ERROR_CHECK(bus_init());

    // Initialize input
    ESP_ERROR_CHECK(input_init());

    // Try to start WIFI
    esp_err_t res = wifi_init();
    if (res != ESP_OK)
        ESP_LOGW(TAG, "Could not start WiFi: %d (%s)", res, esp_err_to_name(res));

    // Create main task
    if (xTaskCreate(main_loop, APP_NAME, MAIN_TASK_STACK_SIZE, NULL, MAIN_TASK_PRIORITY, NULL) != pdPASS)
    {
        ESP_LOGE(TAG, "Could not create main task");
        ESP_ERROR_CHECK(ESP_FAIL);
    }
}

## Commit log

2021-04-27 First prototype
2021-04-30 change default effect params, add button support
2021-04-30 update esp-idf-lib, disable button temporaly
2021-04-30 input poll moved from timer to separate task
2021-04-30 fixed CMakeLists.txt, add on/off func
    [main.c, surface.c]
2021-05-01 fix default effect params, move rendering to app core
    [surface.c]
2021-05-01 add water effect, update esp-idf-lib for workarond Wifi/RMT bug
    [config.h, surface.c]
2021-05-02 update esp-idf-lib, fix WiFi/RMT bug, port libnsgif, add SPIFFS and gifs
    [partitions.csv]
2021-05-03 fix metaballs palette, fix typos, lower log verbosity, fix surface init
    [config.h, surface.c]
2021-05-03 remove spiffs image, update esp-idf-lib
    [partitions.csv]
2021-05-07 api: add POST /api/settings/leds
2021-05-08 flash: OTA partition table, app szie = 0x150000
    [partitions.csv]
2021-05-09 remove libnsgif, remove led_gpio from settings
2021-05-10 added new buttons, throw out fb_animation, cleanup in surface code
2021-05-10 update button defaults
2021-05-10 Add reset button
2021-05-13 web: saving wifi & leds settings, reset, reboot
    [surface.c]
2021-05-19 web: update interface to more suitable for mobile devices
2021-05-19 new effect 'Flower'
2021-05-21 fix surface_prepare_effect(), fix lava params
    [surface.c]
2021-05-24 rename 'rollrays' to 'radiant wheel'
2021-06-02 main: fix button event handler
    [main.c]
2021-07-09 add separate reset button level, update defaults, update esp-idf-lib
2022-04-30 new effect, fix clnag tidy warnings
    [config.h, surface.c]
2022-05-02 Add schematics
    [evlamp.kicad_pcb, evlamp.kicad_sch]
2022-05-05 cpu speed set to 240MHz, small fixes
    [main.c]
2022-05-25 add hw layouts to readme, fix surface init bug, fix 'gif', fix 'hoop'
    [evlamp.kicad_pcb, evlamp.kicad_sch]
2022-05-26 fix readme, add params to 'wheel' and 'twister'
2022-05-26 Fix bug in brightness restriction calculation
    [surface.c]
2022-05-26 workaround ESP-IDF bug with stopping HTTP server on WiFi disconnect
    [main.c]
2022-05-27 update readme, fix max maxtrix dimensions in config.h
    [config.h]
2022-05-28 add KiCad project and Gerber files
    [evlamp-B_Cu.gbl, evlamp-B_Mask.gbs, evlamp-B_Paste.gbp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]
2022-05-29 update KiCad project
    [evlamp-B_Cu.gbl, evlamp-B_Mask.gbs, evlamp-B_Paste.gbp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]
2022-05-29 fix check of led type in api, suppress deprecated rmt warning, first try of surface rotation
    [config.h, surface.c]
2022-06-18 add checkbox support to effect parameters
    [evlamp.kicad_pcb, evlamp.kicad_sch]
2023-11-28 update to ver 0.7.4
    [evlamp.kicad_pcb, evlamp.kicad_sch]
